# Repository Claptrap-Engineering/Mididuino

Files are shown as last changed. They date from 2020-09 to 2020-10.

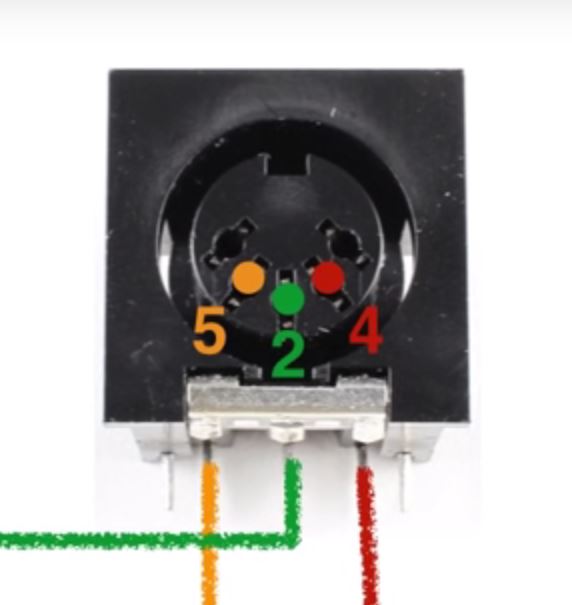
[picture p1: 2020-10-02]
PCB Images/MIDI din plug female pinout.JPG

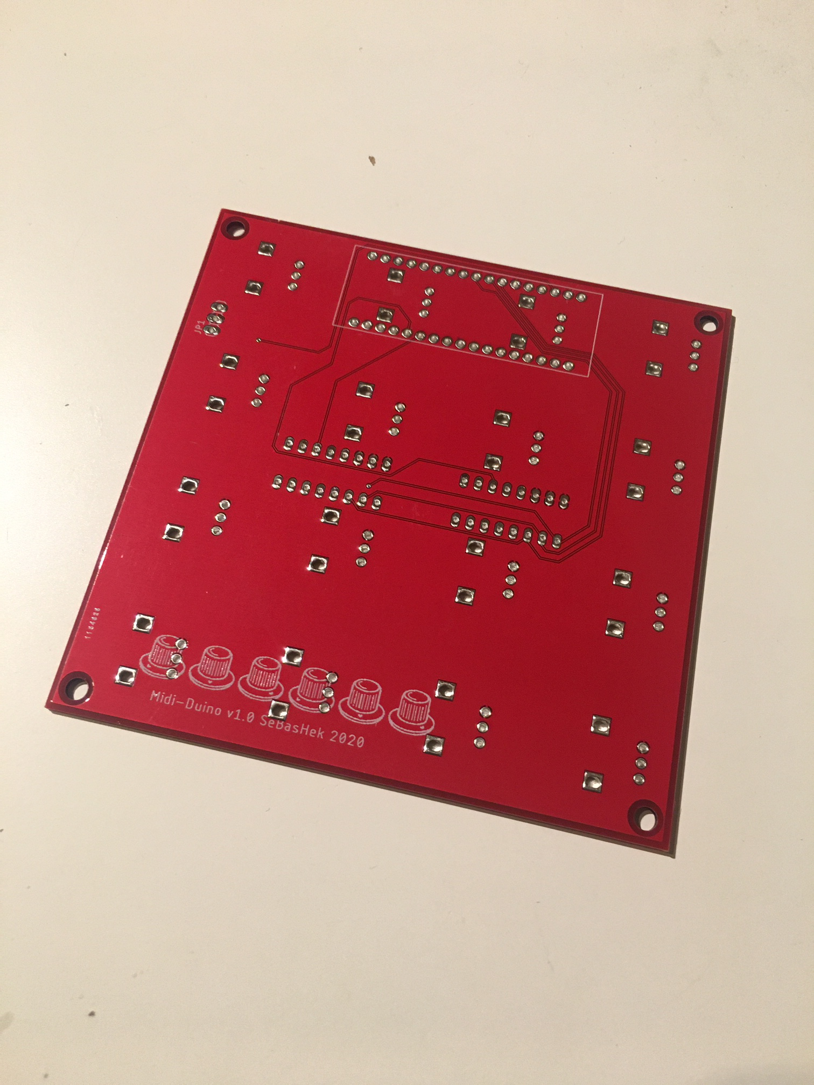
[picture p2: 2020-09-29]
PCB Images/IMG_4414.JPG

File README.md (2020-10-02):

# Midi-duino
A midicontroller based on an arduino nano

The original code can be downloaded from https://drive.google.com/file/d/0BwnVMB_6yujwR1dydVJ6MHJib2M/view
This code is written by Dave from notes and volts @ https://www.notesandvolts.com 
Watch his youtube movies to make your own version of a midi controller.

After toying around on a breadboard and converting this to a solder strip board.
I got annoyed by the prototyping process and started designing a PCB for it.
This project is the result :)

The arduino you click or solder on this board uses the script you can find on this page in the MIDI_controller folder.
It is a configured version of daves original code to fit two multiplexers that read 16 potentiometers.

To make the code work (compile) in the arduino IDE you must install the midi library files.
You can find these at https://github.com/FortySevenEffects/arduino_midi_library/releases/tag/4.2

Notes for soldering:

Solder the parts in the order from small to large.
Solder the two pinheader sockets in the top holes at the back of the board, leaving the two holes open at the bottom,
(when looking at the board in such a way so the printed R potmeter values are in normal reading order)
So that the arduino can be clicked into the sockets at the back of the board. See the images folder for reference pictures.

Din plug pinout (see pinout image in pcb image folder)

Connect pin 1 of the jumpers with pin 5 of the din plug (signal).
Connect pin 2 of the jumpers with pin 2 of the din plug (ground).
Connect pin 3 of the jumpers with pin 4 of the din plug (5v).

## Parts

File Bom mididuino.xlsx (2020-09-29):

part | amount | value | description
r1-r16 | 16 | 10k | 6mm potmeter - ALPS BC103b or better quality
r17-r18 | 2 | 220Ω | SMD resistor 220r 0603
c1-c2 | 2 | 100n | SMD capacitor 100n 0603
IC1-IC2 | 2 | 4051N | M74HC4051B1
Sockets | 2 |  | 15 pin pinheader socket 2.54 PPTC151LFBN-RC
pin header | 1 |  | 3 pinheader
Aduino | 1 | nano | arduino nano or chinese clone
din socket | 1 | 5 pole | 180 degree 5 pole din female socket SD-50SN or equivalent

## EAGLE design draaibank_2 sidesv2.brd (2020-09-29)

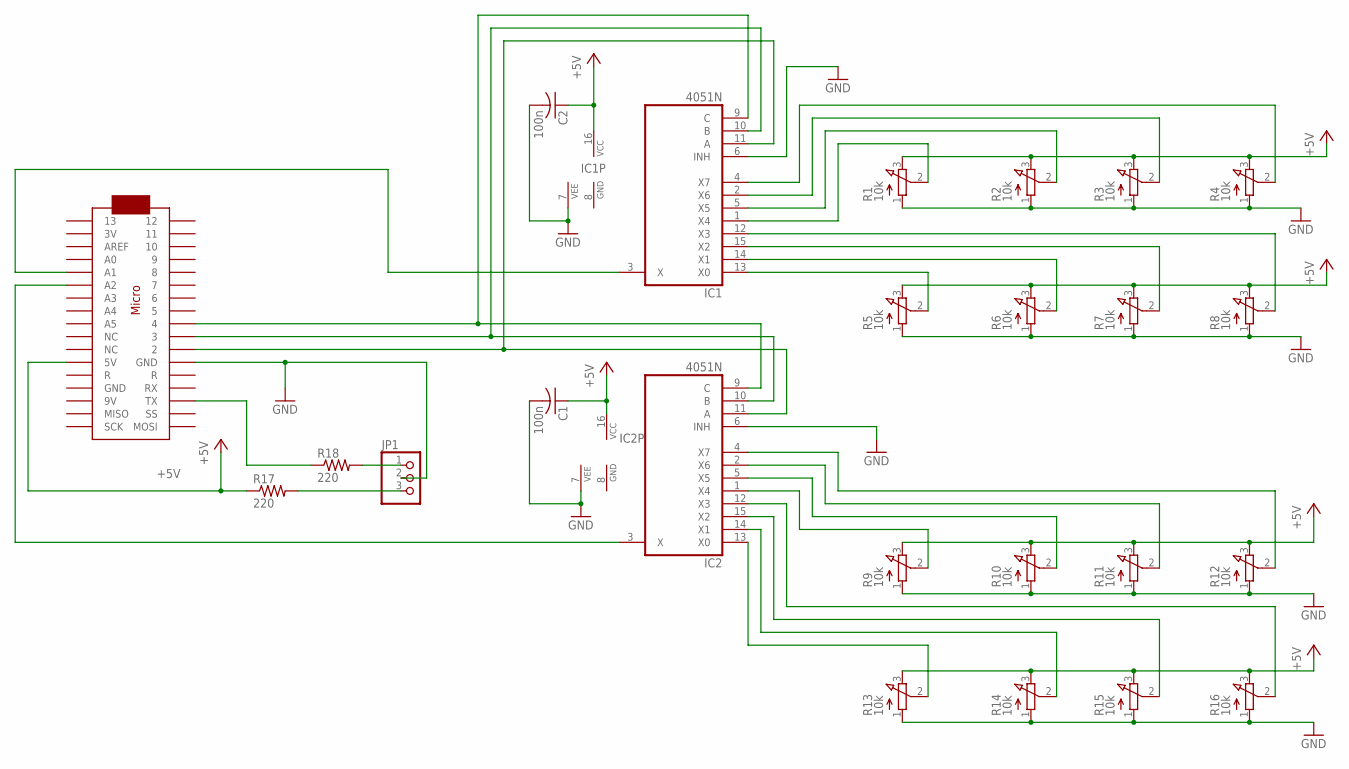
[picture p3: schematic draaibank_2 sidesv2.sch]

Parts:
C1, C2: 100n; C0805
IC1, IC2: 4051N; DIL16
JP1: PINHD-1X3; 1X03
R1, R2, R3, R4, R5, R6, R7, R8, R9, R10, R11, R12, R13, R14, R15, R16: 10k; EVUF
R17, R18: 220; R0603
U$1: ARDUINOMICRO

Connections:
+5V: C1.1, C2.1, IC1.16 (VCC), IC2.16 (VCC), R1.3 (E), R2.3 (E), R3.3 (E), R4.3 (E), R5.3 (E), R6.3 (E), R7.3 (E), R8.3 (E), R9.3 (E), R10.3 (E), R11.3 (E), R12.3 (E), R13.3 (E), R14.3 (E), R15.3 (E), R16.3 (E), R17.1, U$1.P$23 (5V)
GND: C1.2, C2.2, IC1.6 (INH), IC1.7 (VEE), IC1.8 (GND), IC2.6 (INH), IC2.7 (VEE), IC2.8 (GND), JP1.2, R1.1 (A), R2.1 (A), R3.1 (A), R4.1 (A), R5.1 (A), R6.1 (A), R7.1 (A), R8.1 (A), R9.1 (A), R10.1 (A), R11.1 (A), R12.1 (A), R13.1 (A), R14.1 (A), R15.1 (A), R16.1 (A), U$1.P$21 (GND)
unnamed: IC2.13 (X0), R13.2 (S)
unnamed: IC2.14 (X1), R14.2 (S)
unnamed: IC2.15 (X2), R15.2 (S)
unnamed: IC2.12 (X3), R16.2 (S)
unnamed: IC2.1 (X4), R9.2 (S)
unnamed: IC2.5 (X5), R10.2 (S)
unnamed: IC2.2 (X6), R11.2 (S)
unnamed: IC2.4 (X7), R12.2 (S)
unnamed: IC1.13 (X0), R5.2 (S)
unnamed: IC1.14 (X1), R6.2 (S)
unnamed: IC1.15 (X2), R7.2 (S)
unnamed: IC1.12 (X3), R8.2 (S)
unnamed: IC1.1 (X4), R1.2 (S)
unnamed: IC1.5 (X5), R2.2 (S)
unnamed: IC1.2 (X6), R3.2 (S)
unnamed: IC1.4 (X7), R4.2 (S)
unnamed: IC1.11 (A), IC2.11 (A), U$1.P$11 (2)
unnamed: IC1.10 (B), IC2.10 (B), U$1.P$10 (3)
unnamed: IC1.9 (C), IC2.9 (C), U$1.P$9 (4)
unnamed: R18.1, U$1.P$15 (TX)
unnamed: JP1.1, R18.2
unnamed: JP1.3, R17.2
unnamed: IC1.3 (X), U$1.P$30 (A1)
unnamed: IC2.3 (X), U$1.P$29 (A2)

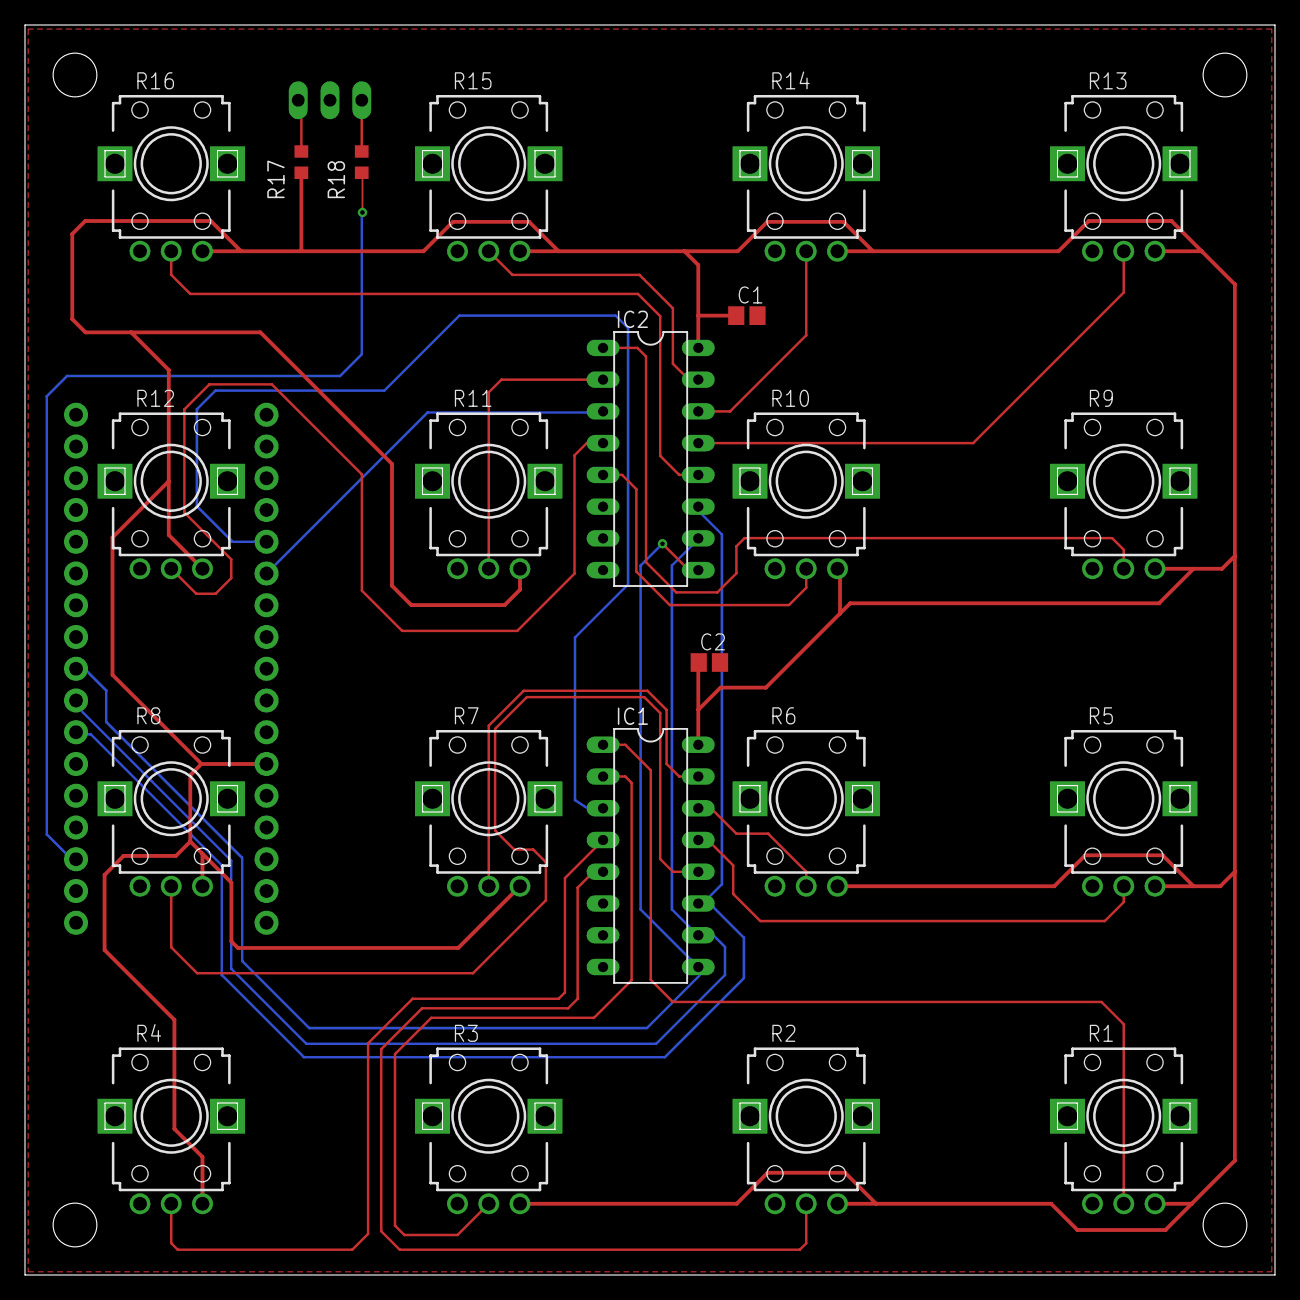
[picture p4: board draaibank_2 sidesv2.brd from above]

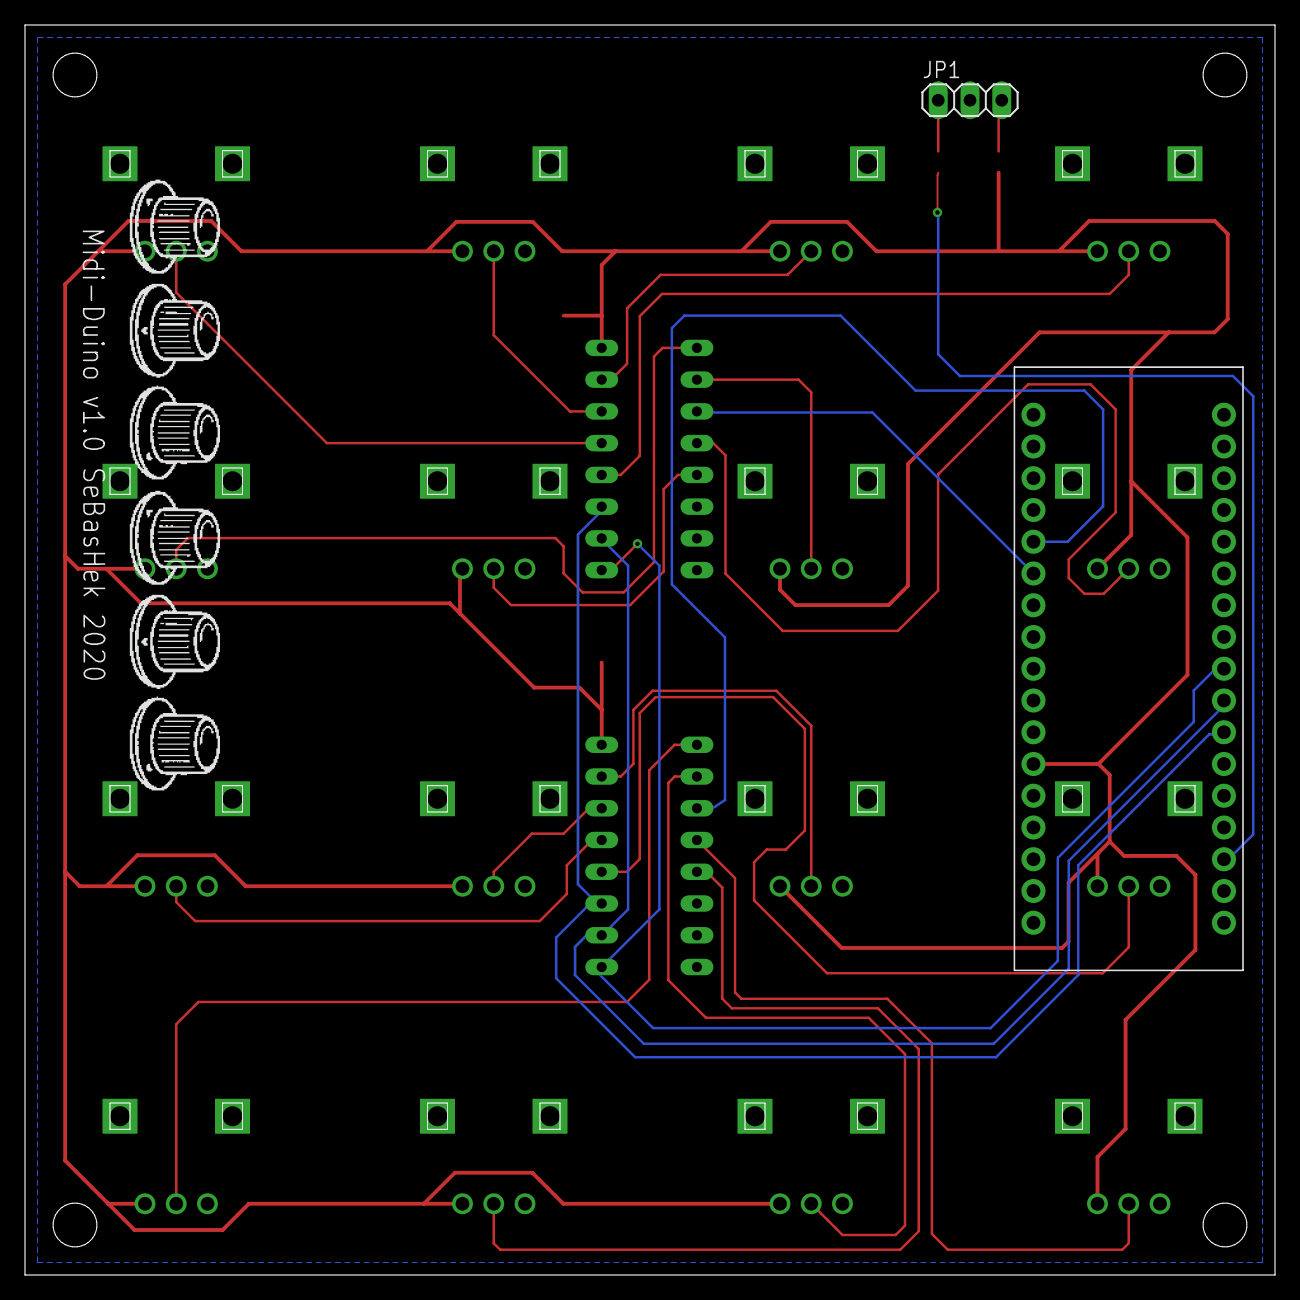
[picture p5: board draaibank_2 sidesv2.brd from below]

Board: 2 copper layers, 100.0 x 100.0 mm, 24 parts (2 on the bottom side), 26 nets.

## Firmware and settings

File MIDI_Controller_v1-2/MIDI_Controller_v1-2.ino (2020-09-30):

#include <MIDI.h>
#include "Controller.h"

/*************************************************************
  MIDI CONTROLLER

  by Notes and Volts
  www.notesandvolts.com

  Version 1.2 **Arduino UNO ONLY!** (ALSO WORKS ON NANO)
 *************************************************************/

MIDI_CREATE_DEFAULT_INSTANCE();

//************************************************************
//***SET THE NUMBER OF CONTROLS USED**************************
//************************************************************
//---How many buttons are connected directly to pins?---------
byte NUMBER_BUTTONS = 0;
//---How many potentiometers are connected directly to pins?--
byte NUMBER_POTS = 0;
//---How many buttons are connected to a multiplexer?---------
byte NUMBER_MUX_BUTTONS = 0;
//---How many potentiometers are connected to a multiplexer?--
byte NUMBER_MUX_POTS = 16;
//************************************************************

//***ANY MULTIPLEXERS? (74HC4067)************************************
//MUX address pins must be connected to Arduino UNO pins 2,3,4,5
//A0 = PIN2, A1 = PIN3, A2 = PIN4, A3 = PIN5
//*******************************************************************
//Mux NAME (OUTPUT PIN, , How Many Mux Pins?(8 or 16) , Is It Analog?);


//Mux M1(10, 16, false); //Digital multiplexer on Arduino pin 10
Mux M1(A1, 8, true); //Analog multiplexer on Arduino analog pin A0
Mux M2(A2, 8, true); //Analog multiplexer on Arduino analog pin A0
//*******************************************************************


//***DEFINE DIRECTLY CONNECTED POTENTIOMETERS************************
//Pot (Pin Number, Command, CC Control, Channel Number)
//**Command parameter is for future use**

//Pot PO1(A0, 0, 1, 1);
//Pot PO2(A1, 0, 10, 1);
//Pot PO3(A2, 0, 22, 1);
//Pot PO4(A3, 0, 118, 1);
//Pot PO5(A4, 0, 30, 1);
//Pot PO6(A5, 0, 31, 1);
//*******************************************************************
//Add pots used to array below like this->  Pot *POTS[] {&PO1, &PO2, &PO3, &PO4, &PO5, &PO6};
Pot *POTS[] {};
//*******************************************************************


//***DEFINE DIRECTLY CONNECTED BUTTONS*******************************
//Button (Pin Number, Command, Note Number, Channel, Debounce Time)
//** Command parameter 0=NOTE  1=CC  2=Toggle CC **

//Button BU1(2, 0, 60, 1, 5 );
//Button BU2(3, 0, 61, 1, 5 );
//Button BU3(4, 0, 62, 1, 5 );
//Button BU4(5, 0, 63, 1, 5 );
//Button BU5(6, 0, 64, 1, 5 );
//Button BU6(7, 0, 65, 1, 5 );
//Button BU7(8, 1, 64, 1, 5 );
//Button BU8(9, 2, 64, 1, 5 );
//*******************************************************************
//Add buttons used to array below like this->  Button *BUTTONS[] {&BU1, &BU2, &BU3, &BU4, &BU5, &BU6, &BU7, &BU8};
Button *BUTTONS[] {};
//*******************************************************************


//***DEFINE BUTTONS CONNECTED TO MULTIPLEXER*************************
//Button::Button(Mux mux, byte muxpin, byte command, byte value, byte channel, byte debounce)
//** Command parameter 0=NOTE  1=CC  2=Toggle CC **

//Button MBU1(M1, 0, 0, 70, 1, 5);
//Button MBU2(M1, 1, 1, 71, 1, 5);
//Button MBU3(M1, 2, 2, 72, 1, 5);
//Button MBU4(M1, 3, 0, 73, 1, 5);
//Button MBU5(M1, 4, 0, 74, 1, 5);
//Button MBU6(M1, 5, 0, 75, 1, 5);
//Button MBU7(M1, 6, 0, 76, 1, 5);
//Button MBU8(M1, 7, 0, 77, 1, 5);
//Button MBU9(M2, 8, 0, 78, 1, 5);
//Button MBU10(M2, 9, 0, 79, 1, 5);
//Button MBU11(M2, 10, 0, 80, 1, 5);
//Button MBU12(M2, 11, 0, 81, 1, 5);
//Button MBU13(M2, 12, 0, 82, 1, 5);
//Button MBU14(M2, 13, 0, 83, 1, 5);
//Button MBU15(M2, 14, 0, 84, 1, 5);
//Button MBU16(M2, 15, 0, 85, 1, 5);
//*******************************************************************
////Add multiplexed buttons used to array below like this->  Button *MUXBUTTONS[] {&MBU1, &MBU2, &MBU3, &MBU4, &MBU5, &MBU6.....};
Button *MUXBUTTONS[] {};

//*******************************************************************


//***DEFINE POTENTIOMETERS CONNECTED TO MULTIPLEXER*******************
//Pot::Pot(Mux mux, byte muxpin, byte command, byte control, byte channel)
//**Command parameter is for future use**

Pot MPO1(M1, 0, 0, 1, 1);
Pot MPO2(M1, 1, 0, 7, 1);
Pot MPO3(M1, 2, 0, 50, 1);
Pot MPO4(M1, 3, 0, 51, 2);
Pot MPO5(M1, 4, 0, 52, 1);
Pot MPO6(M1, 5, 0, 53, 2);
Pot MPO7(M1, 6, 0, 54, 1);
Pot MPO8(M1, 7, 0, 55, 2);
Pot MPO9(M2, 8, 0, 56, 1);
Pot MPO10(M2, 9, 0, 57, 2);
Pot MPO11(M2, 10, 0, 58, 1);
Pot MPO12(M2, 11, 0, 59, 2);
Pot MPO13(M2, 12, 0, 60, 1);
Pot MPO14(M2, 13, 0, 61, 2);
Pot MPO15(M2, 14, 0, 62, 1);
Pot MPO16(M2, 15, 0, 63, 2);

//*******************************************************************
//Add multiplexed pots used to array below like this->  Pot *MUXPOTS[] {&MPO1, &MPO2, &MPO3, &MPO4, &MPO5, &MPO6.....};
Pot *MUXPOTS[] {&MPO1, &MPO2, &MPO3, &MPO4, &MPO5, &MPO6,&MPO7, &MPO8, &MPO9, &MPO10, &MPO11, &MPO12,&MPO13, &MPO14, &MPO15, &MPO16};
//*******************************************************************


void setup() {
  MIDI.begin(MIDI_CHANNEL_OFF);
}

void loop() {
  if (NUMBER_BUTTONS != 0) updateButtons();
  if (NUMBER_POTS != 0) updatePots();
  if (NUMBER_MUX_BUTTONS != 0) updateMuxButtons();
  if (NUMBER_MUX_POTS != 0) updateMuxPots();
}


//*****************************************************************
void updateButtons() {

  // Cycle through Button array
  for (int i = 0; i < NUMBER_BUTTONS; i = i + 1) {
    byte message = BUTTONS[i]->getValue();

    //  Button is pressed
    if (message == 0) {
      switch (BUTTONS[i]->Bcommand) {
        case 0: //Note
          MIDI.sendNoteOn(BUTTONS[i]->Bvalue, 127, BUTTONS[i]->Bchannel);
          break;
        case 1: //CC
          MIDI.sendControlChange(BUTTONS[i]->Bvalue, 127, BUTTONS[i]->Bchannel);
          break;
        case 2: //Toggle
          if (BUTTONS[i]->Btoggle == 0) {
            MIDI.sendControlChange(BUTTONS[i]->Bvalue, 127, BUTTONS[i]->Bchannel);
            BUTTONS[i]->Btoggle = 1;
          }
          else if (BUTTONS[i]->Btoggle == 1) {
            MIDI.sendControlChange(BUTTONS[i]->Bvalue, 0, BUTTONS[i]->Bchannel);
            BUTTONS[i]->Btoggle = 0;
          }
          break;
      }
    }

    //  Button is not pressed
    if (message == 1) {
      switch (BUTTONS[i]->Bcommand) {
        case 0:
          MIDI.sendNoteOff(BUTTONS[i]->Bvalue, 0, BUTTONS[i]->Bchannel);
          break;
        case 1:
          MIDI.sendControlChange(BUTTONS[i]->Bvalue, 0, BUTTONS[i]->Bchannel);
          break;
      }
    }
  }
}
//*******************************************************************
void updateMuxButtons() {

  // Cycle through Mux Button array
  for (int i = 0; i < NUMBER_MUX_BUTTONS; i = i + 1) {

    MUXBUTTONS[i]->muxUpdate();
    byte message = MUXBUTTONS[i]->getValue();

    //  Button is pressed
    if (message == 0) {
      switch (MUXBUTTONS[i]->Bcommand) {
        case 0: //Note
          MIDI.sendNoteOn(MUXBUTTONS[i]->Bvalue, 127, MUXBUTTONS[i]->Bchannel);
          break;
        case 1: //CC
          MIDI.sendControlChange(MUXBUTTONS[i]->Bvalue, 127, MUXBUTTONS[i]->Bchannel);
          break;
        case 2: //Toggle
          if (MUXBUTTONS[i]->Btoggle == 0) {
            MIDI.sendControlChange(MUXBUTTONS[i]->Bvalue, 127, MUXBUTTONS[i]->Bchannel);
            MUXBUTTONS[i]->Btoggle = 1;
          }
          else if (MUXBUTTONS[i]->Btoggle == 1) {
            MIDI.sendControlChange(MUXBUTTONS[i]->Bvalue, 0, MUXBUTTONS[i]->Bchannel);
            MUXBUTTONS[i]->Btoggle = 0;
          }
          break;
      }
    }
    //  Button is not pressed
    if (message == 1) {
      switch (MUXBUTTONS[i]->Bcommand) {
        case 0:
          MIDI.sendNoteOff(MUXBUTTONS[i]->Bvalue, 0, MUXBUTTONS[i]->Bchannel);
          break;
        case 1:
          MIDI.sendControlChange(MUXBUTTONS[i]->Bvalue, 0, MUXBUTTONS[i]->Bchannel);
          break;
      }
    }
  }
}
//***********************************************************************
void updatePots() {
  for (int i = 0; i < NUMBER_POTS; i = i + 1) {
    byte potmessage = POTS[i]->getValue();
    if (potmessage != 255) MIDI.sendControlChange(POTS[i]->Pcontrol, potmessage, POTS[i]->Pchannel);
  }
}
//***********************************************************************
void updateMuxPots() {
  for (int i = 0; i < NUMBER_MUX_POTS; i = i + 1) {
    MUXPOTS[i]->muxUpdate();
    byte potmessage = MUXPOTS[i]->getValue();
    if (potmessage != 255) MIDI.sendControlChange(MUXPOTS[i]->Pcontrol, potmessage, MUXPOTS[i]->Pchannel);
  }
}

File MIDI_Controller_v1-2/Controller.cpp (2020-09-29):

#include "Controller.h"

//****************************************************************************************
Mux::Mux(byte outpin_, byte numPins_, bool analog_)
{
  outpin = outpin_;
  //enablepin = enablepin_;
  numPins = numPins_;
  analog = analog_;
  if (analog == false) pinMode(outpin, INPUT_PULLUP);
  //pinMode(enablepin, OUTPUT);
  pinMode(2, OUTPUT);
  pinMode(3, OUTPUT);
  pinMode(4, OUTPUT);
  if (numPins > 8) pinMode(5, OUTPUT);
}
//****************************************************************************************
//Button (Pin Number, Command, Note Number, Channel, Debounce Time)
Button::Button(byte pin, byte command, byte value, byte channel, byte debounce)
{
  _pin = pin;
  pinMode(_pin, INPUT_PULLUP);
  _value = value;
  _command = command;
  _debounce = debounce;
  _time = 0;
  _busy = false;
  _status = 0b00000010;
  _last = 1;
  Bcommand = command;
  Bvalue = value;
  Bchannel = channel;
  Btoggle = 0;
}

Button::Button(Mux mux, byte muxpin, byte command, byte value, byte channel, byte debounce)
{
  _pin = mux.outpin;
  _numMuxPins = mux.numPins;
  _muxpin = muxpin;
  _value = value;
  _command = command;
  _debounce = debounce;
  _time = 0;
  _busy = false;
  _status = 0b00000010;
  _last = 1;
  Bcommand = command;
  Bvalue = value;
  Bchannel = channel;
  Btoggle = 0;
}

void Button::muxUpdate()
{
  byte temp = _muxpin;
  temp = temp << 2;
  if (_numMuxPins > 8) PORTD = PORTD & B11000011;
  else PORTD = PORTD & B11100011;
  PORTD = PORTD | temp;
}

byte Button::getValue()
{
  // If BUSY bit not set - read button
  if (bitRead(_status, 0) == false) { // If busy false
    if (digitalRead(_pin) == _last) return 2; // If same as last state - exit
  }

  // If NEW Bit set - Key just pressed, record time
  if (bitRead(_status, 1) == true) { // If new is true
    bitSet(_status, 0); // Set busy TRUE
    bitClear(_status, 1); // Set New FALSE
    _time = millis();
    return 255;
  }

  // Check if debounce time has passed - If no, exit
  if (millis() - _time < _debounce) return 255;

  // Debounce time has passed. Read pin to see if still set the same
  // If it has changed back - assume false alarm
  if (digitalRead(_pin) == _last) {
    bitClear(_status, 0); // Set busy false
    bitSet(_status, 1); // Set new true
    return 255;
  }

  // If this point is reached, event is valid. return event type
  else {
    bitClear(_status, 0); // Set busy false
    bitSet(_status, 1); // Set new true
    _last = ((~_last) & 0b00000001); // invert _last
    return _last;
  }
}

void Button::newValue(byte command, byte value, byte channel)
{
  Bvalue = value;
  Bcommand = command;
  Bchannel = channel;
}

//********************************************************************
Pot::Pot(byte pin, byte command, byte control, byte channel)
{
  _pin = pin;
  _control = control;
  _value = analogRead(_pin);
  _value = _value >> 3;
  _oldValue = _value << 3;
  _value = _value << 3;
  Pcommand = command;
  Pcontrol = control;
  Pchannel = channel;
}

void Pot::muxUpdate()
{
  byte temp = _muxpin;
  temp = temp << 2;
  if (_numMuxPins > 8) PORTD = PORTD & B11000011;
  else PORTD = PORTD & B11100011;
  //PORTD = PORTD & B11000011;
  PORTD = PORTD | temp;
}

Pot::Pot(Mux mux, byte muxpin, byte command, byte control, byte channel)
{
  _pin = mux.outpin;
  _numMuxPins = mux.numPins;
  _muxpin = muxpin;
  _control = control;
  muxUpdate();
  _value = analogRead(_pin);
  _value = _value >> 3;
  _oldValue = _value << 3;
  _value = _value << 3;
  Pcommand = command;
  Pcontrol = control;
  Pchannel = channel;
}

byte Pot::getValue()
{
  _value = analogRead(_pin);
  int tmp = (_oldValue - _value);
  if (tmp >= 8 || tmp <= -8) {
    _oldValue = _value >> 3;
    _oldValue = _oldValue << 3;
    return _value >> 3;
  }
  return 255;
}

void Pot::newValue(byte command, byte value, byte channel) {
  Pcommand = command;
  Pcontrol = value;
  Pchannel = channel;
}

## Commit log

2020-09-29 Add files via upload
    Adapted arduino script to make use of 16 potmeters
2020-09-30 Update MIDI_Controller_v1-2.ino
    changed mux ports to A1 and A2 as routed on mididuino board v1
